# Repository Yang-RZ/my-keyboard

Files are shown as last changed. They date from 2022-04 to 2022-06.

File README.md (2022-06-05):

# MyKeyboard

* 该键盘是我为了更快地敲代码而给自己设计
* 本方案借鉴了如下两个项目:
  - https://github.com/SEASKY-Master/keyboard
  - https://github.com/diabolo38/HidKbd
* 本方案中的原理图是用立创EDA设计的
* RightControl键被设计用来切换键层
  - 一层为正常键盘
  - 二层用F1~F4实现多媒体键
  - 最初设计不支持切换层, 用RightControl作为切换键的话会和Ctrl+-快捷键冲突, 先取消这个功能了, 可以在代码里添加宏WITH_MULTIMEDIA_KEY来启用.
* 成品图
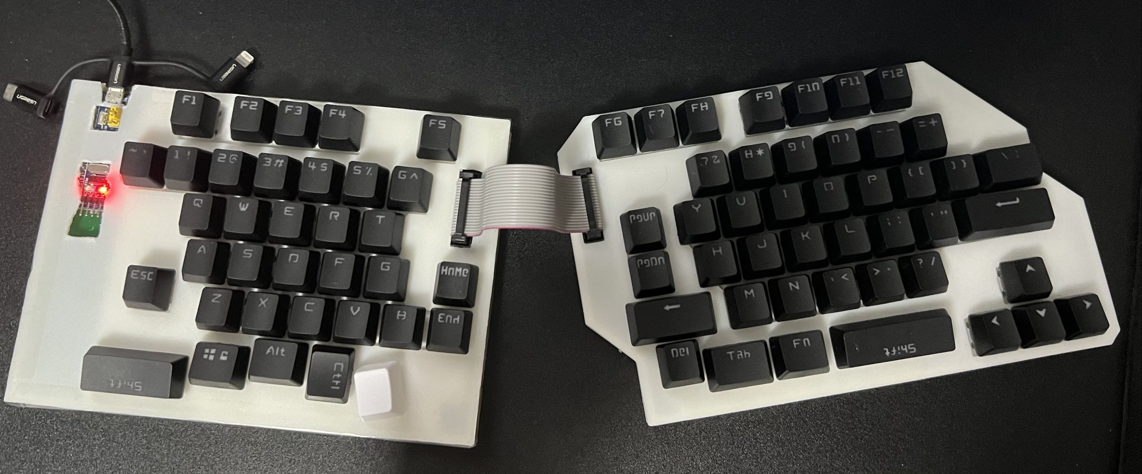
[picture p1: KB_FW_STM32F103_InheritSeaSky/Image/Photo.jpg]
  
* 重量
  - 625.5g

* 成本：
  - STM32F103最小系统板，20
  - PCB板，都是5块板，无铅喷锡，包括快递费：左半边110，右半边130。平均一个键盘48
  - N4148贴片二极管，大概5.6
  - 可插拔轴座，35
  - JTAG插头和排线，3.1
  - 键盘轴，3块一个，大概220
  - 键帽，15
  - 3D打印定位板和外壳，估计100g材料，7块钱
  - 共计350左右

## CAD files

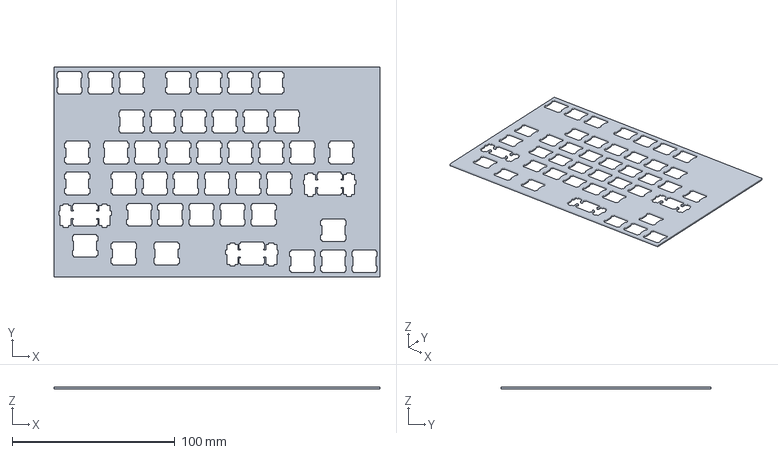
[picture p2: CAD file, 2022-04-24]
KB_FW_STM32F103_InheritSeaSky/Drawing/RightHalf.3MF
200.0 x 128.6 x 1.50 mm

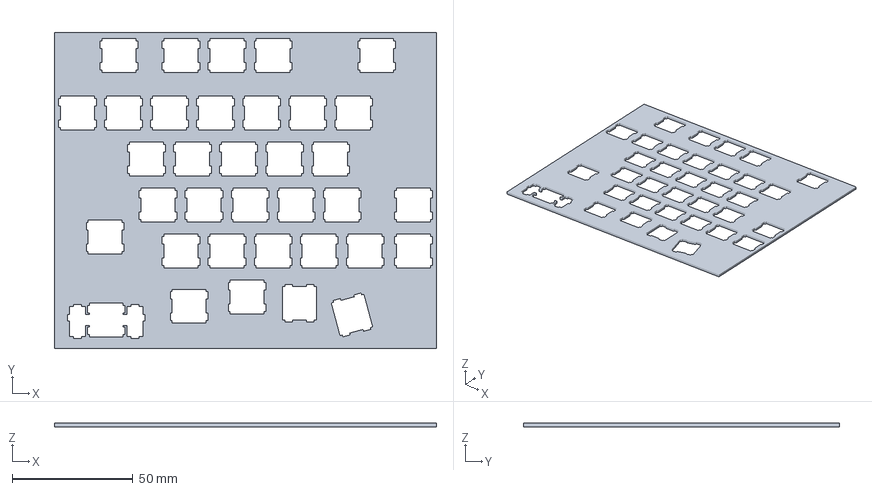
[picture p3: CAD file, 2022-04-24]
KB_FW_STM32F103_InheritSeaSky/Drawing/LeftHalf.3MF
158.1 x 130.9 x 1.50 mm

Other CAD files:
KB_FW_STM32F103_InheritSeaSky/Drawing/lefthalf.dxf
KB_FW_STM32F103_InheritSeaSky/Drawing/righthalf.dxf

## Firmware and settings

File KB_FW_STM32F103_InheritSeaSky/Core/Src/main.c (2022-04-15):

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
/* Includes ------------------------------------------------------------------*/
#include "main.h"
#include "usb_device.h"

/* USER CODE BEGIN Includes */
#include "key_event.h"
#include "bsp_key.h"
/* USER CODE END Includes */

 RTC_HandleTypeDef hrtc;

/* USER CODE BEGIN PV */
// extern USBD_HandleTypeDef hUsbDeviceFS;
uint8_t fac_us;
key_info_t key_info;
/* USER CODE END PV */

void SystemClock_Config(void);
static void MX_GPIO_Init(void);
static void MX_RTC_Init(void);
/**
  * @brief  The application entry point.
  * @retval int
  */
int main(void)
{
  /* MCU Configuration--------------------------------------------------------*/

  /* Reset of all peripherals, Initializes the Flash interface and the Systick. */
  HAL_Init();

  /* Configure the system clock */
  SystemClock_Config();

  /* Initialize all configured peripherals */
  MX_GPIO_Init();
  MX_RTC_Init();
  MX_USB_DEVICE_Init();
  /* USER CODE BEGIN 2 */
// uint8_t txbuffer[8]= {0x00,0x00,0x00,0x00,0x00,0x00,0x00,0x00};//�?
// uint8_t sendbuffer[8]={0x00,0x00,0x2c,0x00,0x00,0x00,0x00,0x00};//空格
	mx_key_init(&key_info);
	mx_key_init_layer1(&key_info);
  /* USER CODE END 2 */

  /* Infinite loop */
  /* USER CODE BEGIN WHILE */
  while (1)
  {
    /* USER CODE END WHILE */

    /* USER CODE BEGIN 3 */
    detect_key_events();
// USBD_HID_SendReport(&hUsbDeviceFS,sendbuffer,8);//发�?�报�?
// HAL_Delay(5000);
  }
  /* USER CODE END 3 */
}

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


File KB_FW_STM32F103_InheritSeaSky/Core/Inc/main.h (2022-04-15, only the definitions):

#define R0_Pin GPIO_PIN_13
#define R0_GPIO_Port GPIOC
#define R1_Pin GPIO_PIN_14
#define R1_GPIO_Port GPIOC
#define R2_Pin GPIO_PIN_15
#define R2_GPIO_Port GPIOC
#define R3_Pin GPIO_PIN_0
#define R3_GPIO_Port GPIOA
#define R4_Pin GPIO_PIN_1
#define R4_GPIO_Port GPIOA
#define R5_Pin GPIO_PIN_2
#define R5_GPIO_Port GPIOA
#define C0_Pin GPIO_PIN_3
#define C0_GPIO_Port GPIOA
#define C1_Pin GPIO_PIN_4
#define C1_GPIO_Port GPIOA
#define C2_Pin GPIO_PIN_5
#define C2_GPIO_Port GPIOA
#define C3_Pin GPIO_PIN_6
#define C3_GPIO_Port GPIOA
#define C4_Pin GPIO_PIN_7
#define C4_GPIO_Port GPIOA
#define C5_Pin GPIO_PIN_0
#define C5_GPIO_Port GPIOB
#define C6_Pin GPIO_PIN_1
#define C6_GPIO_Port GPIOB
#define C7_Pin GPIO_PIN_10
#define C7_GPIO_Port GPIOB
#define R6_Pin GPIO_PIN_12
#define R6_GPIO_Port GPIOB
#define R7_Pin GPIO_PIN_13
#define R7_GPIO_Port GPIOB
#define R8_Pin GPIO_PIN_14
#define R8_GPIO_Port GPIOB
#define R9_Pin GPIO_PIN_15
#define R9_GPIO_Port GPIOB
#define R10_Pin GPIO_PIN_8
#define R10_GPIO_Port GPIOA
#define R11_Pin GPIO_PIN_9
#define R11_GPIO_Port GPIOA
#define C8_Pin GPIO_PIN_10
#define C8_GPIO_Port GPIOA
#define C11_Pin GPIO_PIN_15
#define C11_GPIO_Port GPIOA
#define C12_Pin GPIO_PIN_3
#define C12_GPIO_Port GPIOB
#define C13_Pin GPIO_PIN_4
#define C13_GPIO_Port GPIOB
#define C14_Pin GPIO_PIN_5
#define C14_GPIO_Port GPIOB
#define C15_Pin GPIO_PIN_6
#define C15_GPIO_Port GPIOB
#define C16_Pin GPIO_PIN_7
#define C16_GPIO_Port GPIOB
#define C17_Pin GPIO_PIN_8
#define C17_GPIO_Port GPIOB
#define C18_Pin GPIO_PIN_9
#define C18_GPIO_Port GPIOB

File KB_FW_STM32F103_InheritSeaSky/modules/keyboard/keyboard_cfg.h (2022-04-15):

#ifndef _KEYBOARD_CFG_H
#define _KEYBOARD_CFG_H
#include "struct_typedef.h"
#include "usb_hid_keys.h"
#define MAX_KEYPAD_PAGE 104
#define STACK_POINT_LENGTH 6
/*键盘按键枚举*/
typedef enum
{
    Key_board_Null = 0,
    Keyboard_a =4,// Keyboard a and A
    Keyboard_b=5,// Keyboard b and B
    Keyboard_c=6,// Keyboard c and C
    Keyboard_d=7,// Keyboard d and D
    Keyboard_e=8,// Keyboard e and E
    Keyboard_f=9,// Keyboard f and F
    Keyboard_g=10,// Keyboard g and G
    Keyboard_h=11,// Keyboard h and H
    Keyboard_i=12,// Keyboard i and I
    Keyboard_j=13,// Keyboard j and J
    Keyboard_k=14,// Keyboard k and K
    Keyboard_l=15,// Keyboard l and L
    Keyboard_m=16,// Keyboard m and M
    Keyboard_n=17,// Keyboard n and N
    Keyboard_o=18,// Keyboard o and O
    Keyboard_p=19,// Keyboard p and P
    Keyboard_q=20,// Keyboard q and Q
    Keyboard_r=21,// Keyboard r and R
    Keyboard_s=22,// Keyboard s and S
    Keyboard_t=23,// Keyboard t and T
    Keyboard_u=24,// Keyboard u and U
    Keyboard_v=25,// Keyboard v and V
    Keyboard_w=26,// Keyboard w and W
    Keyboard_x=27,// Keyboard x and X
    Keyboard_y=28,// Keyboard y and Y
    Keyboard_z=29,// Keyboard z and Z
    Keyboard_1=30,// Keyboard 1 and !
    Keyboard_2=31,// Keyboard 2 and @
    Keyboard_3=32,// Keyboard 3 and #
    Keyboard_4=33,// Keyboard 4 and $
    Keyboard_5=34,// Keyboard 5 and %
    Keyboard_6=35,// Keyboard 6 and ^
    Keyboard_7=36,// Keyboard 7 and &
    Keyboard_8=37,// Keyboard 8 and *
    Keyboard_9=38,// Keyboard 9 and (
    Keyboard_0=39,// Keyboard 0 and )
    Keyboard_ENTER=40,// Keyboard ENTER 
    Keyboard_ESCAPE=41,// Keyboard ESCAPE
    Keyboard_Backspace=42,// Keyboard Backspace
    Keyboard_Tab=43,// Keyboard Tab
    Keyboard_KongGe=44,// Keyboard Spacebar
    Keyboard_JianHao=45,// Keyboard - and _(underscore)
    Keyboard_DengHao=46,// Keyboard = and +
    Keyboard_ZuoZhongKuoHao=47,// Keyboard [ and {
    Keyboard_YouZhongKuoHao=48,// Keyboard ] and }
    Keyboard_FanXieGang= 49,// Keyboard \ and |
    Keyboard_FenHao=51,// Keyboard ; and :
    Keyboard_DanYinHao= 52,// Keyboard ‘ and “
    Keyboard_BoLangXian= 53,// Keyboard `(Grave Accent) and ~(Tilde)
    Keyboard_Douhao=54,// Keyboard, and <
    Keyboard_JuHao=55,// Keyboard . and >
    Keyboard_XieGang_WenHao=56,// Keyboard / and ?
    Keyboard_CapsLock=57,// Keyboard Caps Lock
    Keyboard_F1=58,// Keyboard F1
    Keyboard_F2=59,// Keyboard F2
    Keyboard_F3=60,// Keyboard F3
    Keyboard_F4=61,// Keyboard F4
    Keyboard_F5=62,// Keyboard F5
    Keyboard_F6=63,// Keyboard F6
    Keyboard_F7=64,// Keyboard F7
    Keyboard_F8=65,// Keyboard F8
    Keyboard_F9=66,// Keyboard F9
    Keyboard_F10= 67,// Keyboard F10
    Keyboard_F11= 68,// Keyboard F11
    Keyboard_F12= 69,// Keyboard F12
    Keyboard_PrintScreen=70,// Keyboard PrintScreen
    Keyboard_ScrollLock= 71,// Keyboard Scroll Lock
    Keyboard_Pause=72,// Keyboard Pause
    Keyboard_Insert=73,// Keyboard Insert
    Keyboard_Home= 74,// Keyboard Home
    Keyboard_PageUp=75,// Keyboard PageUp
    Keyboard_Delete=76,// Keyboard Delete
    Keyboard_End=77,// Keyboard End
    Keyboard_PageDown=78,// Keyboard PageDown
    Keyboard_RightArrow=79,// Keyboard RightArrow
    Keyboard_LeftArrow=80,// Keyboard LeftArrow
    Keyboard_DownArrow= 81,// Keyboard DownArrow
    Keyboard_UpArrow=82,// Keyboard UpArrow
    Keypad_NumLock=83,// Keypad Num Lock and Clear
    Keypad_ChuHao=84,// Keypad /
    Keypad_ChengHao=85,// Keypad *
    Keypad_JianHao=86,// Keypad -
    Keypad_JiaHao=87,// Keypad +
    Keypad_ENTER=88,// Keypad ENTER
    Keypad_1_and_End=89,// Keypad 1 and End
    Keypad_2_and_DownArrow=90,// Keypad 2 and Down Arrow
    Keypad_3_and_PageDn= 91,// Keypad 3 and PageDn
    Keypad_4_and_LeftArrow=92,// Keypad 4 and Left Arrow
    Keypad_5=93,			// Keypad 5
    Keypad_6_and_RightArrow=94,// Keypad 6 and Right Arrow
    Keypad_7_and_Home=95,// Keypad 7 and Home
    Keypad_8_and_UpArrow=96,// Keypad 8 and Up Arrow
    Keypad_9_and_PageUp= 97,// Keypad 9 and PageUp
    Keypad_0_and_Insert= 98,// Keypad 0 and Insert
    Keypad_Dian_and_Delete=99,// Keypad . and Delete
    Keyboard_Application=101,// Keyboard Application
	Keyboard_Menu=118,

    keyboard_Mute=0xE2,
    keyboard_VolumnUp=0xE9,
    keyboard_VolumnDown=0xEA,
    keyboard_MEDIA_PREVIOUSSONG=0xB6,
    keyboard_MEDIA_PLAYPAUSE=0xCD,
    keyboard_MEDIA_NEXTSONG=0xB5,
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

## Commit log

2022-04-15 Initial version.
    [Code_Assist.xlsx, stlink.cfg, stm32f1x.cfg]
2022-04-17 Layer switching function conflict with RightControl +- composite key.
2022-04-24 Add drawings.
    [LeftHalf.3MF, RightHalf.3MF, lefthalf.dxf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]
2022-06-05 Fix a bug that causes unnecessary KeyUp event before triggering LongPress.
    [bsp_key.c]

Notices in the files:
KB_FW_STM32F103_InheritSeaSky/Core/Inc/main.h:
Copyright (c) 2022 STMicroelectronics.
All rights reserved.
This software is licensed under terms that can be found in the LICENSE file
